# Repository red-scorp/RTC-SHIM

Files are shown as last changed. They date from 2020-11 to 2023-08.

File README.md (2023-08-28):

# RTC-SHIM project

RTC-SHIM (mini-HAT), a DS3231 battery driven real-time clock for Raspberry Pi.

"How did it come to this?" you may ask.
The answer is simple.
I was pissed off by the fact the several Pis I have all have the same issue.
They lose time information when they switched off and need Internet to set proper time again.
The obvious reason for this is lack of RTC chip and backup battery to count time when main CPU of Pi is off.
This is how it's done in all modern PCs and notebooks (and Macs too).
I've searched Internet and found no solution which suits my needs.

- The RTC board should be mounted on 40-pin connector of Raspberry Pi (like 2, 3, 4, zero have).
- The board should be mechanically and electrically compatible with all modern Pis (3+, 4, zero WH).
- The board should be mounted inside or outside the Pi's case.
- There should be possible to put some Pi HAT (Hardware Attached on Top) on top of the board (like LCD display, LoRa, LEDs array or 3G/4G modem HATs).
- The board should be obviously small enough to fit in case of Pi.
- The board should have a battery holder or/and a common notebook BIOS battery connector.
- The board should be easy to setup under Pi's Linux (like Raspbian or Ubuntu).
- The board should be cheap to buy or/and easy to manufacture by (my) hand at home.

And gradually I came with few designs presented here.

## RTC-SHIM

Raspberry Pi 40-pin **RTC-SHIM** mini-HAT.

Preview:

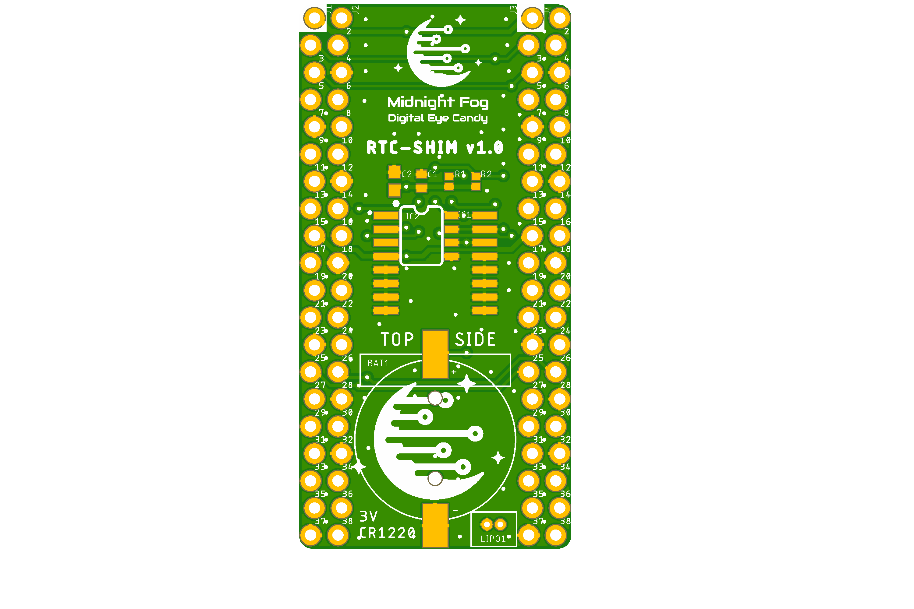
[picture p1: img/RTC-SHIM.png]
RTC-SHIM preview


[Schematics in PDF format](doc/RTC-SHIM.pdf)

Features:

- DS3231 RTC chip
- double footprint for larger and smaller versions of the chip
- CR1220 3V battery
- locked Pi headers
- double set of Pi headers (for inside and outside mount)
- I2C0/I2C1 bus selection
- can be used as SHIM (no headers) or HAT (with headers)
- optional external notebook BIOS battery connector

CAM files are available.

## RTC-mini-flip-SHIM

Raspberry Pi **RTC-mini-flip-SHIM** micro-HAT.

Preview:

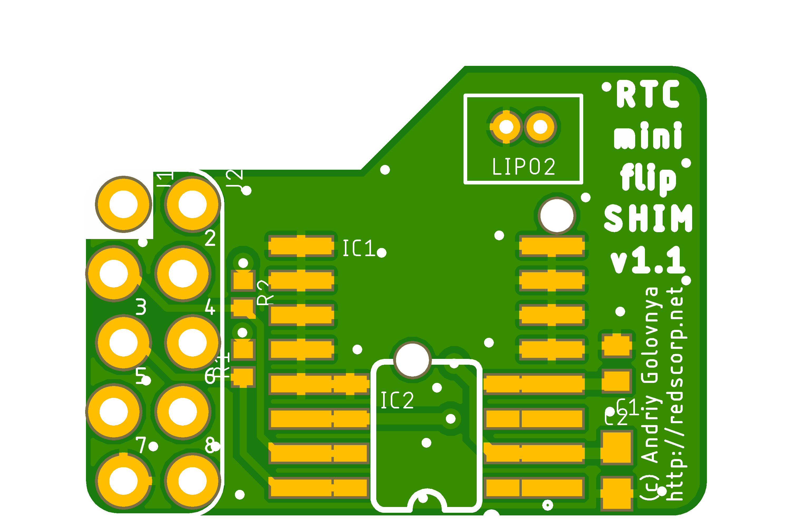
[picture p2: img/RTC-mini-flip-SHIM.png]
RTC-mini-flip-SHIM preview


[Schematics in PDF format](doc/RTC-mini-flip-SHIM.pdf)

Features:

- DS3231 RTC chip
- double footprint for larger and smaller versions of the chip
- CR1220 3V battery
- locked Pi headers
- double mount on Pi headers (for inside and outside mount)
- very small size
- fits on 26- and 40-pin Pi headers
- optional external notebook BIOS battery connector (both side mount possible)

CAM files are available.

## RTC-zero-SHIM

Raspberry Pi zero 40-pin **RTC-zero-SHIM** mini-HAT.

Preview:

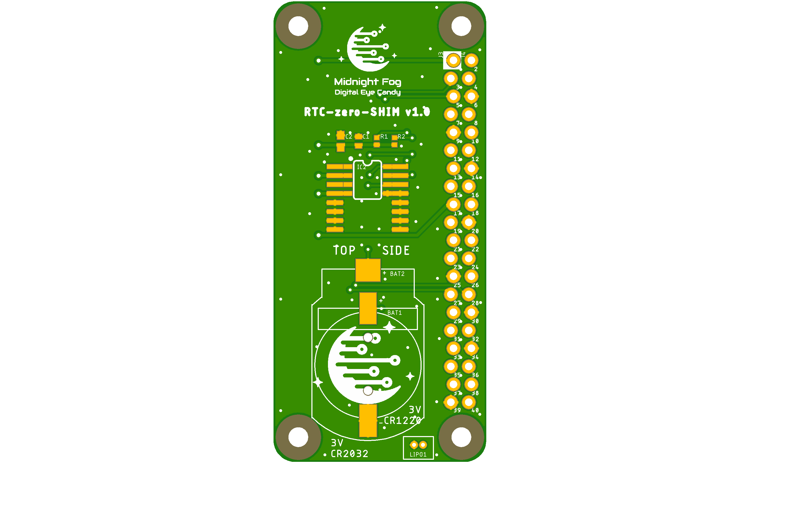
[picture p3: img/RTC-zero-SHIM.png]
RTC-zero-SHIM preview


[Schematics in PDF format](doc/RTC-zero-SHIM.pdf)

Features:

- DS3231 RTC chip
- double footprint for larger and smaller versions of the chip
- CR2032/CR1220 3V battery
- locked Pi headers
- Pi zero board style
- I2C0/I2C1 bus selection
- can be used as SHIM (no headers) or HAT (with headers)
- optional external notebook BIOS battery connector

CAM files are available.

## BOM

Bill Of Materials is currently available only for LCSC Electronic Components Distributor, which is probably cheapest anyway.

### LCSC BOM

|Designator  |Part/Value  |Package/Footprint |LCSC # |
|---|---|---|---|
|BAT1 |CR1220-2 |SMD |C70381 |
|BAT2 |BS-8-1 |SMD |C70378 |
|C1\*\* |Cap. 100nF  |0402 |C1525  |
|C2\*\* |Cap. 1uF |0603 |C15849 |
|IC1\* |DS3231SN#T&R|SOIC-16_300mil |C9866  |
|IC2\* |DS3231MZ+TRL|SOIC-8_150mil |C107410|
|LIPO1, LIPO2|A1251WV-2P  |Through Hole,P=1.25mm |C225090|
|R1, R2\*\*  |Res. 10K |0402 |C25744 |

\*) Only one of chips should be installed, either IC1 or IC2.
\*\*) These passive components are optional but it's recommended to install them.

## Links

- [pinout.xyz](https://pinout.xyz/) - a brilliant resource on topic of Pi's pinout and HATs.
- [raspberrypi/hats](https://github.com/raspberrypi/hats) - Pi's HAT specification.
- [RPI_RTC_Module_SKU:EP-0016](https://wiki.52pi.com/index.php/RPI_RTC_Module_SKU:EP-0016) - some RTC schematics and setup info.
- [Raspberry Pi RTC: Adding a Real Time Clock](https://pimylifeup.com/raspberry-pi-rtc/) - RTC setup info.

## How to help

Your contributions as code, resources, or finances are welcome! Please contact me directly via email at andriy.golovnya@gmail.com or through my [GitHub profile](https://github.com/red-scorp).

If you'd like to make a financial contribution, you can donate via [PayPal](http://paypal.me/redscorp) or [Ko-Fi](http://ko-fi.com/redscorp). Your support is greatly appreciated.

Thanks in advance!

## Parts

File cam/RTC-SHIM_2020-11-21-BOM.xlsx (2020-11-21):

Qty | Designator | Footprint | Comment | LCSC Part # | Description
1 | C1 | 0402 | 100nF | C1525 (https://lcsc.com/product-detail/Multilayer-Ceramic-Capacitors-MLCC-SMD-SMT_SAMSUNG_CL05B104KO5NNNC_100nF-104-10-16V_C1525.html/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) | CAPACITOR
2 | R1, R2 | 0402 | 10K | C25744 (https://lcsc.com/product-detail/Chip-Resistor-Surface-Mount_Uniroyal-Elec-0402WGF1002TCE_C25744.html/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) | RESISTOR
1 | C2 | 0603 | 1uF | C15849 (https://lcsc.com/product-detail/Multilayer-Ceramic-Capacitors-MLCC-SMD-SMT_SAMSUNG_CL10A105KB8NNNC_1uF-105-10-50V_C15849.html/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) | CAPACITOR
1 | IC1 | SOIC-16_7.5x10.3x1.27P | DS3231M+TRL | C37663 (https://lcsc.com/product-detail/Real-time-Clocks_MAXIM_DS3231M-TRL_DS3231M-TRL_C37663.html/?href=jlc-SMT) | RTC Chip

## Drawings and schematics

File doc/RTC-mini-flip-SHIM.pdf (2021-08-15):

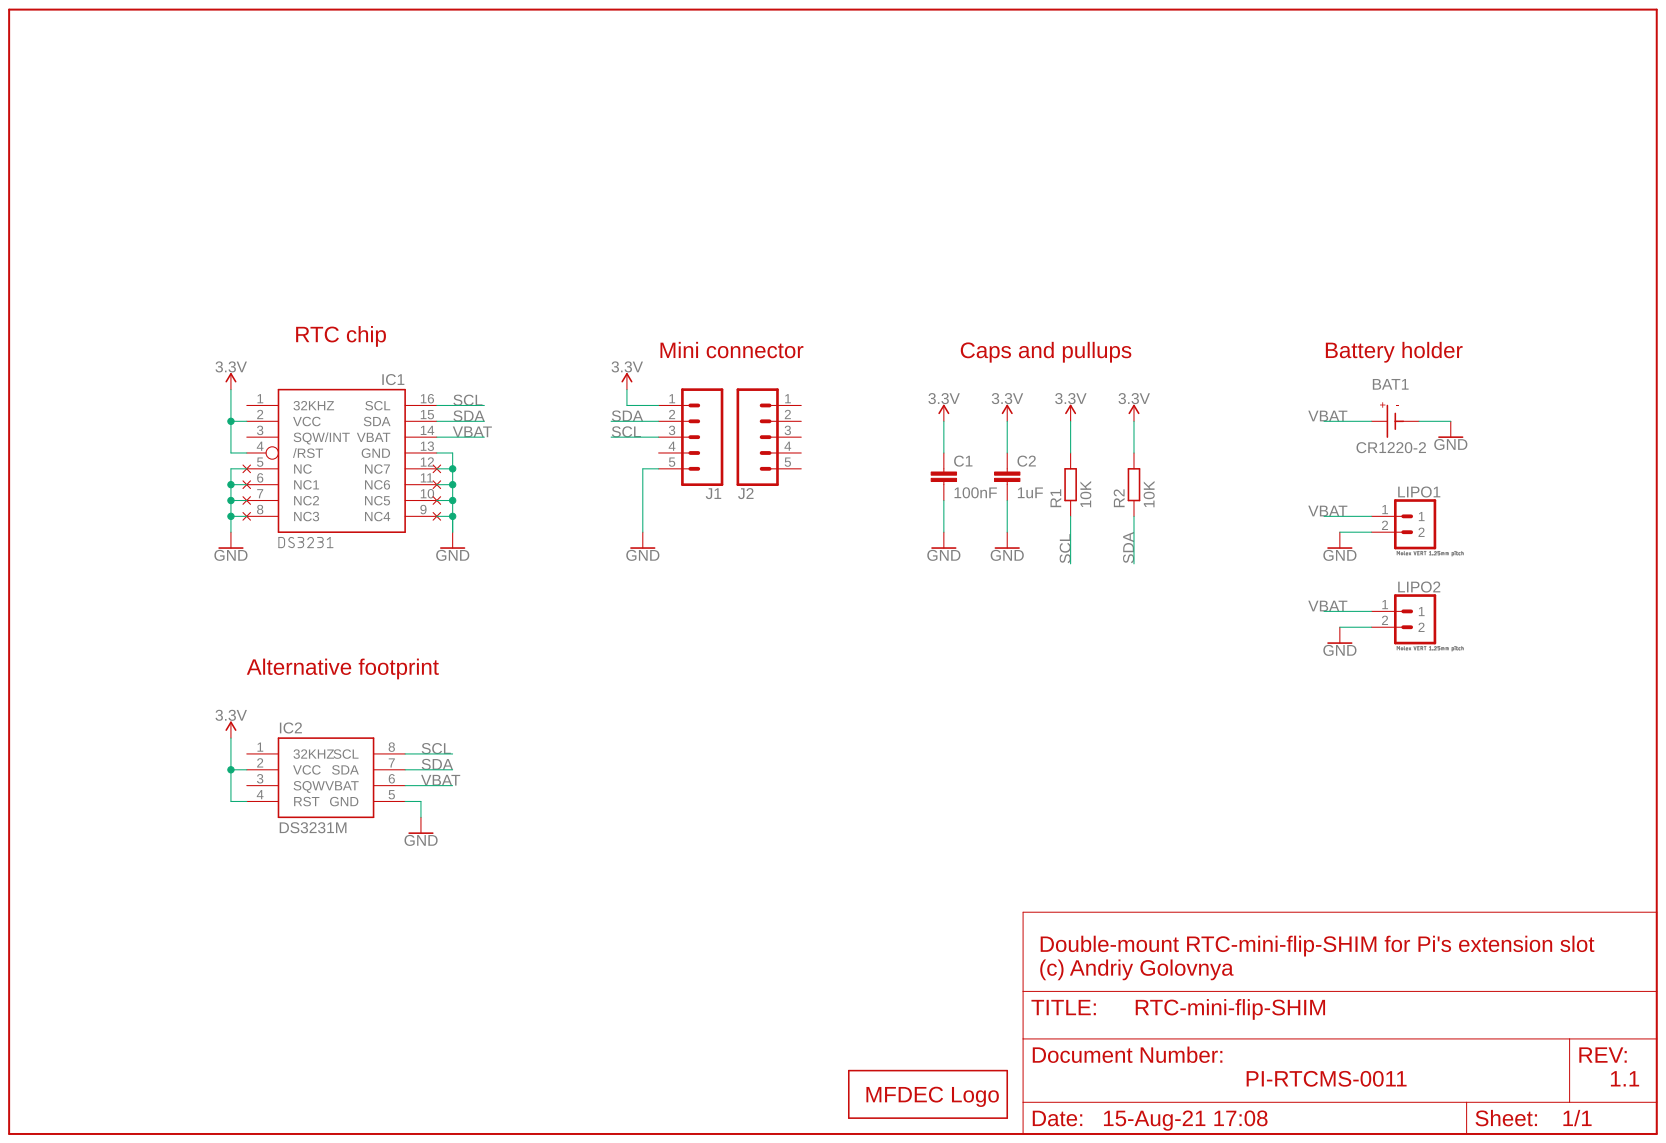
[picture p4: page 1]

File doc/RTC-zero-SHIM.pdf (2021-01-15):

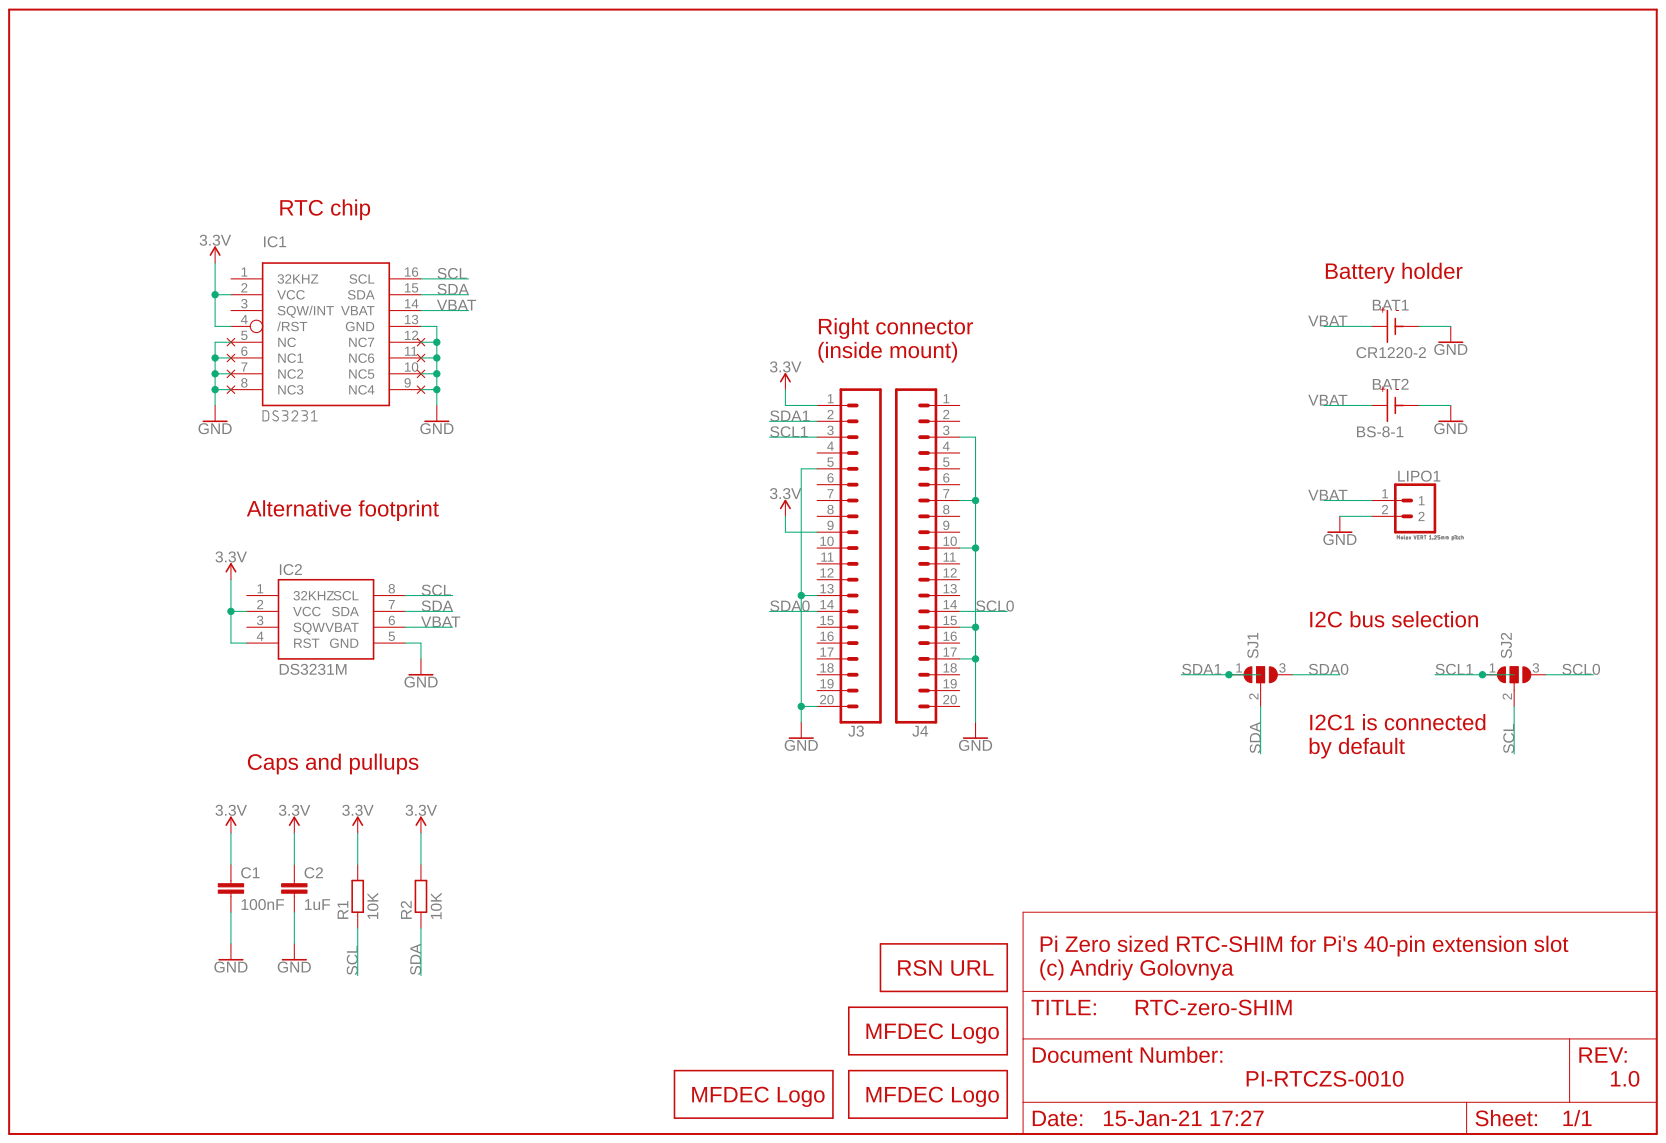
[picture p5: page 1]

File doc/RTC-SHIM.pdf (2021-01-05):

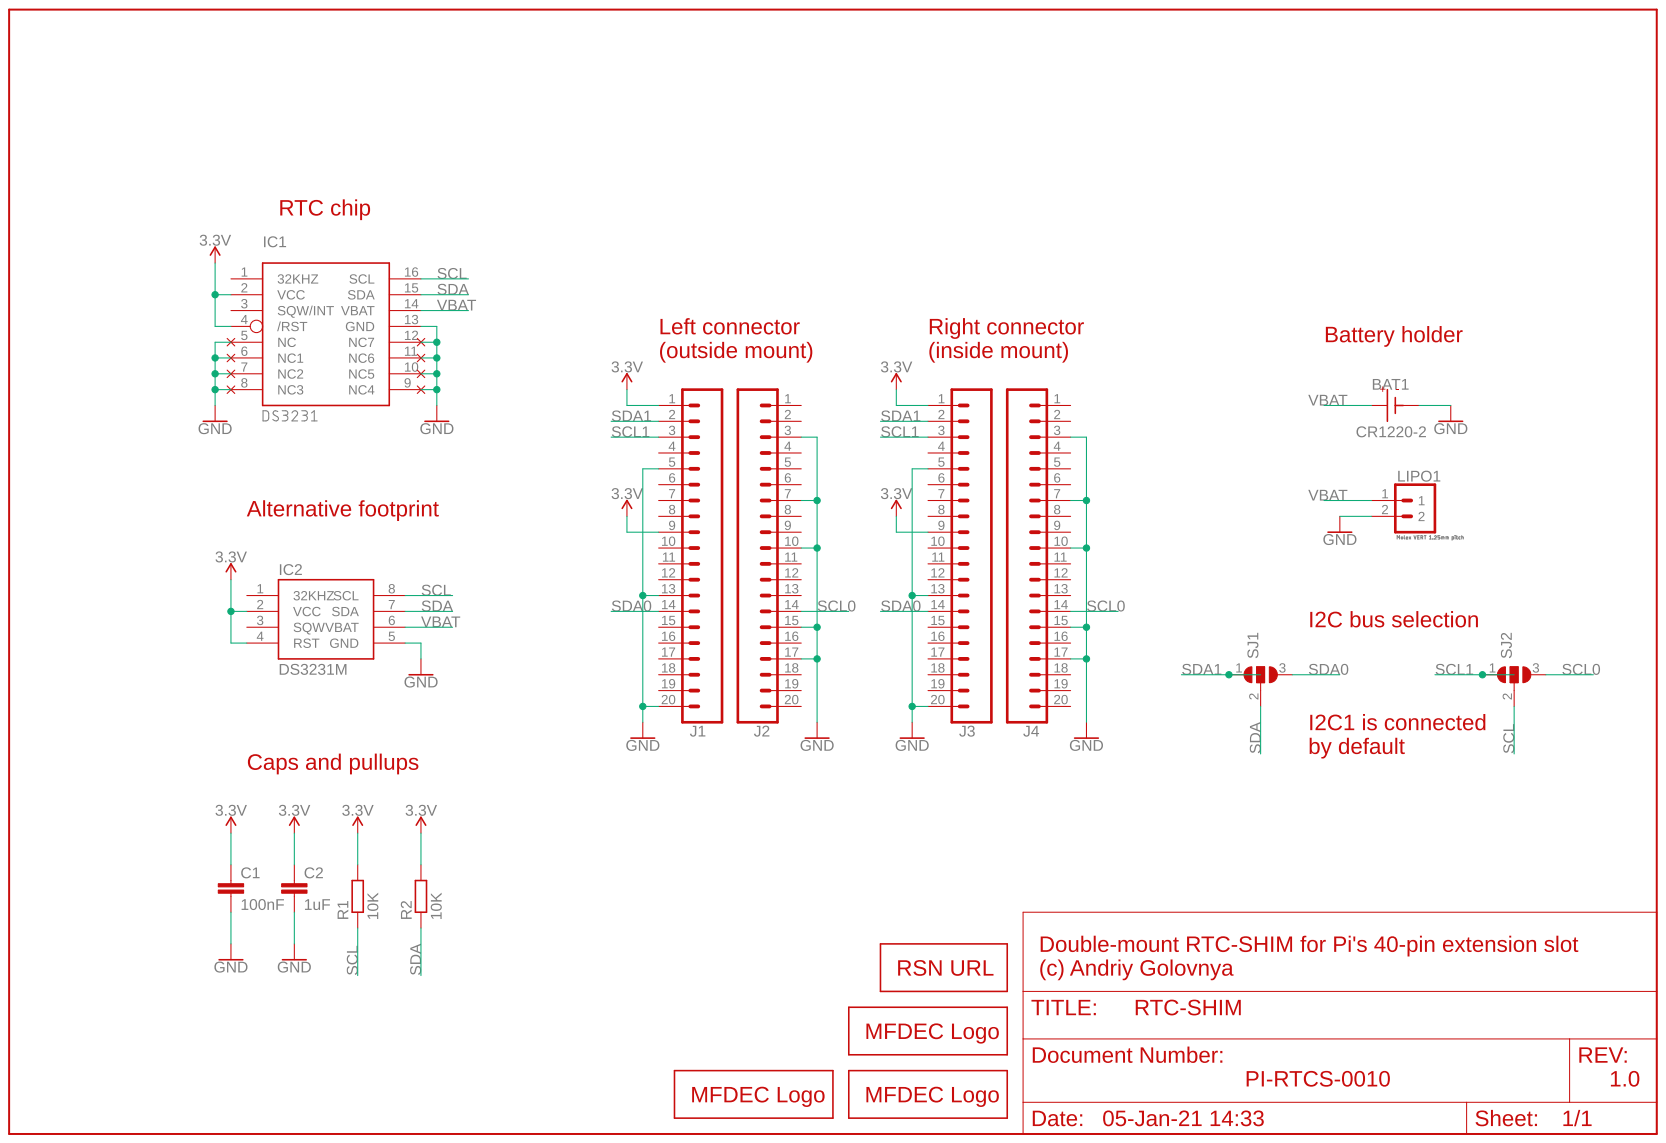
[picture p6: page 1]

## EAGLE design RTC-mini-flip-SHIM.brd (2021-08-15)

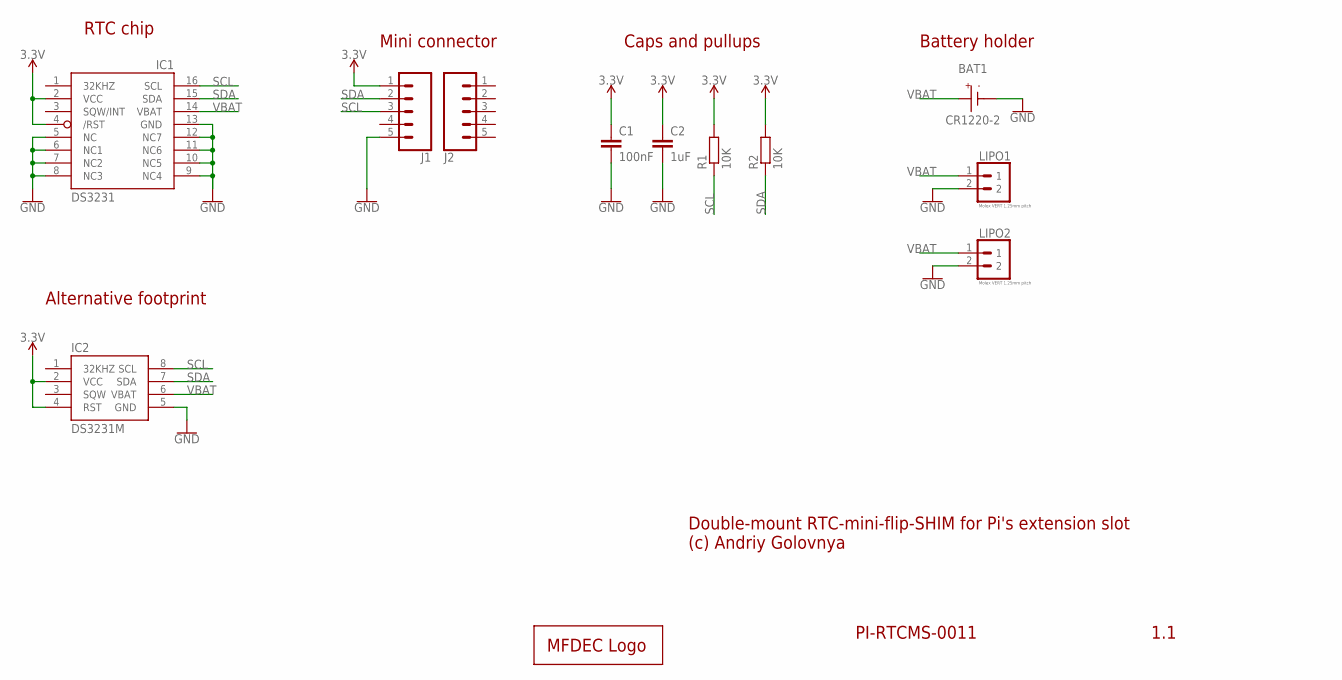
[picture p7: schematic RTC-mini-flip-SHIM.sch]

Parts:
BAT1: CR1220-2
C1: 100nF; C0402
C2: 1uF; C0603
IC1: DS3231/SO; SO16W
IC2: DS3231M; SO08
J1, J2: CONN_05LOCK; 1X05_LOCK
LIPO1, LIPO2: Molex VERT 1.25mm pitch; _MOLEX-0530470210_VERT_PITCH-1.25MM
LOGO1: MFDECLOGO_L_10MM; MFDEC_L_10MM
R1, R2: 10K; R0402

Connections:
3.3V: C1.1, C2.1, IC1.2 (VCC), IC1.4 (/RST), IC2.2 (VCC), IC2.4 (RST), J1.1, R1.2, R2.2
GND: BAT1.BAT-, C1.2, C2.2, IC1.5 (NC), IC1.6 (NC1), IC1.7 (NC2), IC1.8 (NC3), IC1.9 (NC4), IC1.10 (NC5), IC1.11 (NC6), IC1.12 (NC7), IC1.13 (GND), IC2.5 (GND), J1.5, LIPO1.2, LIPO2.2
SCL: IC1.16 (SCL), IC2.8 (SCL), J1.3, R1.1
SDA: IC1.15 (SDA), IC2.7 (SDA), J1.2, R2.1
VBAT: BAT1.BAT+, IC1.14 (VBAT), IC2.6 (VBAT), LIPO1.1, LIPO2.1

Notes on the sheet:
1.1
PI-RTCMS-0011
Double-mount RTC-mini-flip-SHIM for Pi's extension slot (c) Andriy Golovnya
RTC chip
Caps and pullups
Mini connector
Battery holder
Alternative footprint

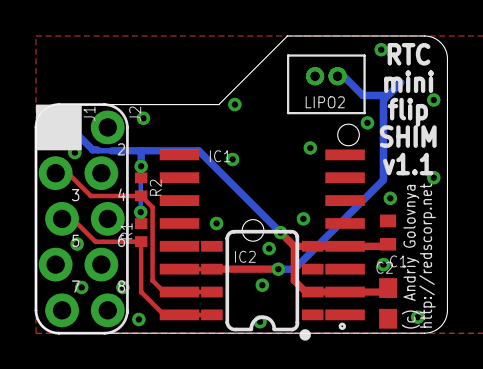
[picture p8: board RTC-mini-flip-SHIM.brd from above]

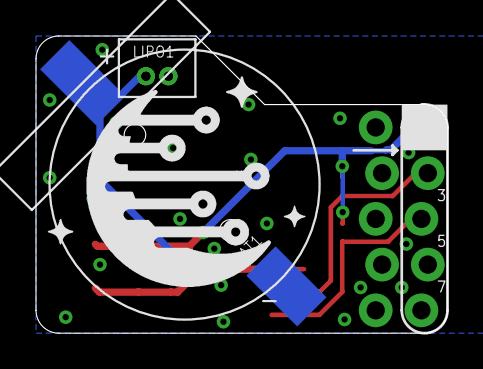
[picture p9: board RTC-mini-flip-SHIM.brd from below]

Board: 2 copper layers, 22.9 x 16.5 mm, 12 parts (3 on the bottom side), 5 nets.

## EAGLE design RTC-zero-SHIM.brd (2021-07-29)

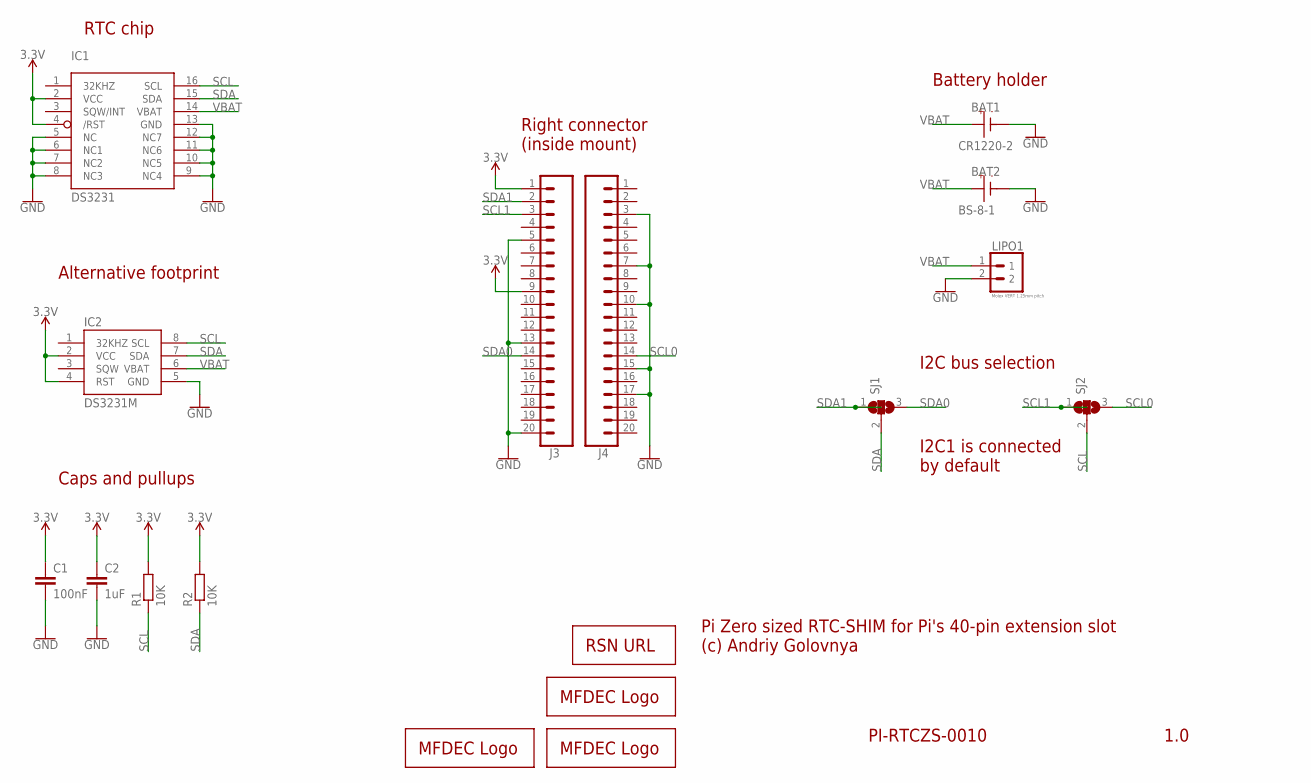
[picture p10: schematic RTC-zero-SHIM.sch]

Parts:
BAT1: CR1220-2
BAT2: BS-8-1
C1: 100nF; C0402
C2: 1uF; C0603
IC1: DS3231/SO; SO16W
IC2: DS3231M; SO08
J3, J4: CONN_20LOCK; 1X20_LOCK
LIPO1: Molex VERT 1.25mm pitch; _MOLEX-0530470210_VERT_PITCH-1.25MM
LOGO1: MFDECLOGO_SQ_8MM; MFDEC_SQ_8MM
LOGO2: MFDECLOGO_L_30MM; MFDEC_L_30MM
LOGO3: RSNURL_QR_10MM
LOGO4: MFDECLOGO_L_10MM; MFDEC_L_10MM
R1, R2: 10K; R0402
SJ1, SJ2: SJ2; SJ_2

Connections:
3.3V: C1.1, C2.1, IC1.2 (VCC), IC1.4 (/RST), IC2.2 (VCC), IC2.4 (RST), J3.1, J3.9, R1.2, R2.2
GND: BAT1.BAT-, BAT2.BAT-, C1.2, C2.2, IC1.5 (NC), IC1.6 (NC1), IC1.7 (NC2), IC1.8 (NC3), IC1.9 (NC4), IC1.10 (NC5), IC1.11 (NC6), IC1.12 (NC7), IC1.13 (GND), IC2.5 (GND), J3.5, J3.13, J3.20, J4.3, J4.7, J4.10, J4.15, J4.17, LIPO1.2
SCL: IC1.16 (SCL), IC2.8 (SCL), R1.1, SJ2.2
SCL0: J4.14, SJ2.3
SCL1: J3.3, SJ2.1
SDA: IC1.15 (SDA), IC2.7 (SDA), R2.1, SJ1.2
SDA0: J3.14, SJ1.3
SDA1: J3.2, SJ1.1
VBAT: BAT1.BAT+, BAT2.BAT+, IC1.14 (VBAT), IC2.6 (VBAT), LIPO1.1

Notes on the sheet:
1.0
PI-RTCZS-0010
Pi Zero sized RTC-SHIM for Pi's 40-pin extension slot (c) Andriy Golovnya
RTC chip
Caps and pullups
Right connector (inside mount)
I2C bus selection
I2C1 is connected by default
Battery holder
Alternative footprint

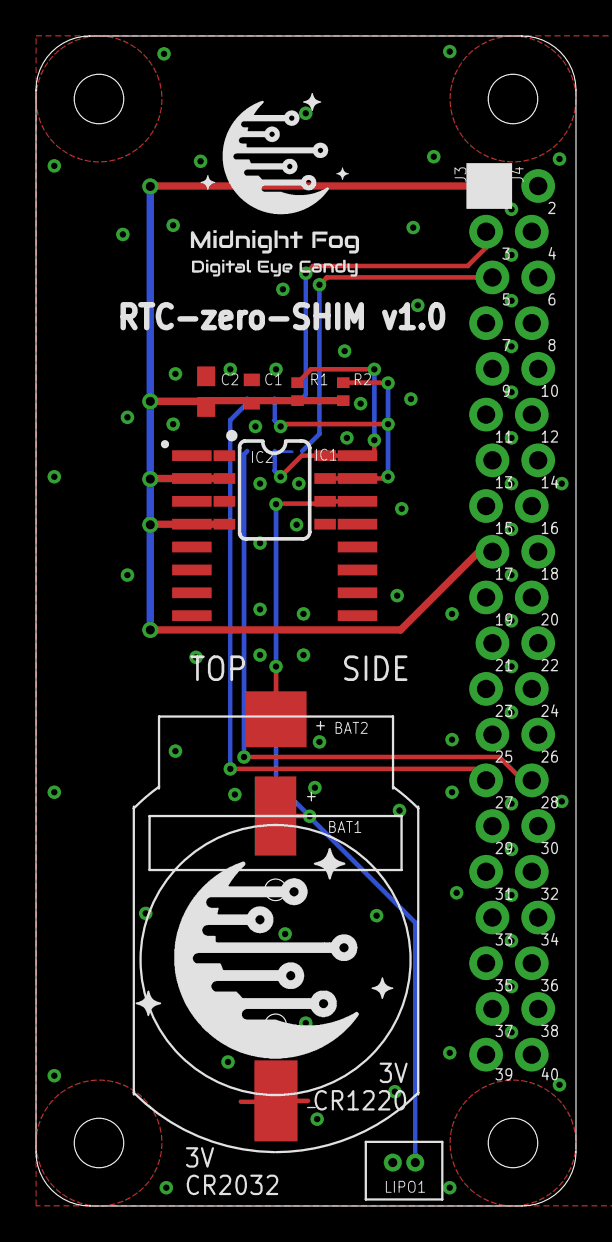
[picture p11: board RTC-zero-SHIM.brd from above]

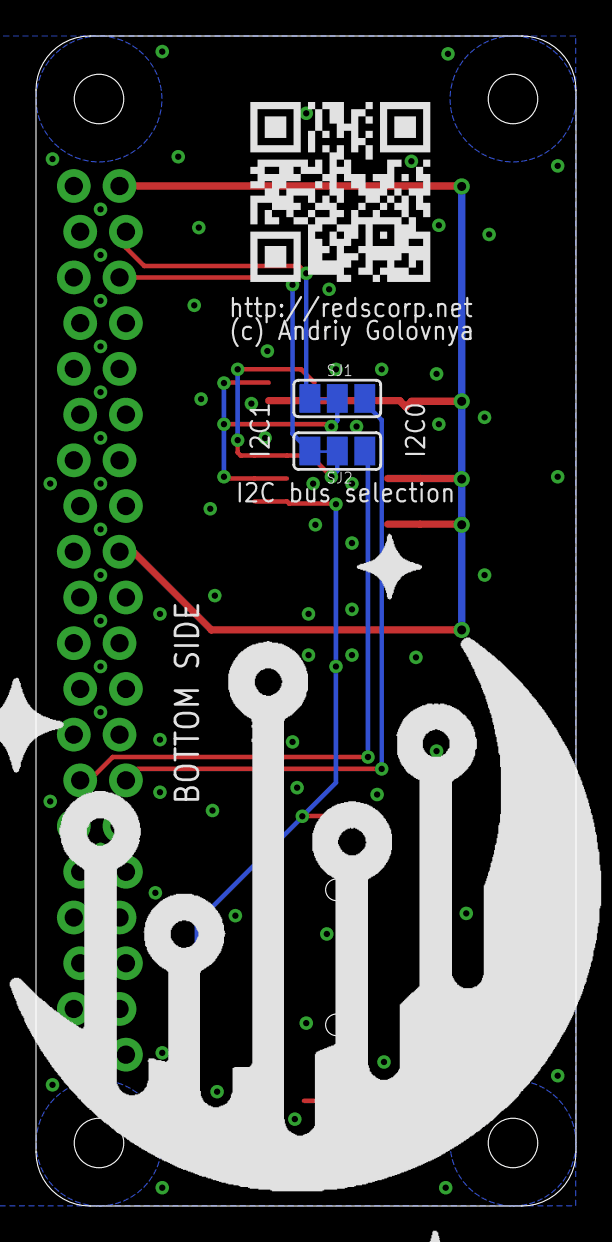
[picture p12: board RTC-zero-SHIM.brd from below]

Board: 2 copper layers, 30.0 x 65.0 mm, 17 parts (4 on the bottom side), 9 nets.

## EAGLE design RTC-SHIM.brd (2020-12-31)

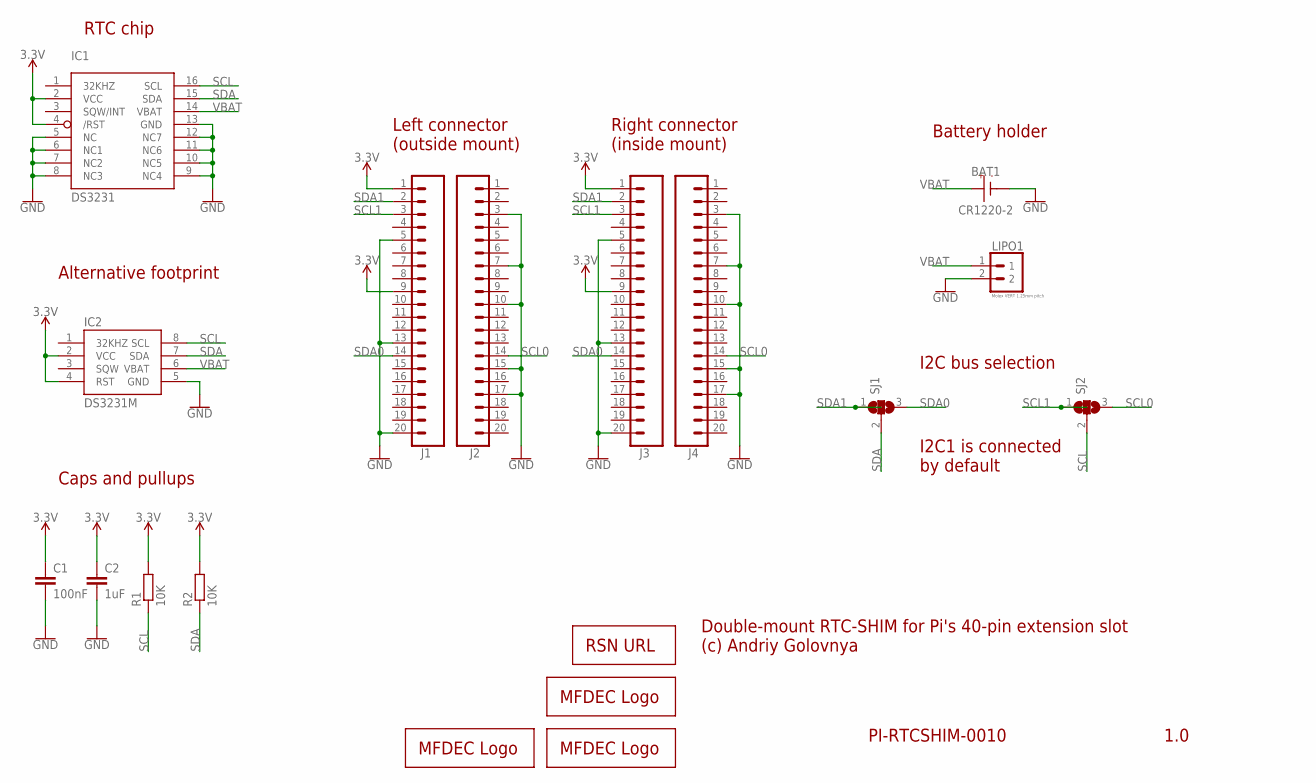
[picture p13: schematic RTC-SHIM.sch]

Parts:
BAT1: CR1220-2
C1: 100nF; C0402
C2: 1uF; C0603
IC1: DS3231/SO; SO16W
IC2: DS3231M; SO08
J1, J2, J3, J4: CONN_20LOCK; 1X20_LOCK
LIPO1: Molex VERT 1.25mm pitch; _MOLEX-0530470210_VERT_PITCH-1.25MM
LOGO1: MFDECLOGO_SQ_8MM; MFDEC_SQ_8MM
LOGO2: MFDECLOGO_L_20MM; MFDEC_L_20MM
LOGO3: RSNURL_QR_10MM
LOGO4: MFDECLOGO_L_10MM; MFDEC_L_10MM
R1, R2: 10K; R0402
SJ1, SJ2: SJ2; SJ_2

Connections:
3.3V: C1.1, C2.1, IC1.2 (VCC), IC1.4 (/RST), IC2.2 (VCC), IC2.4 (RST), J1.1, J1.9, J3.1, J3.9, R1.2, R2.2
GND: BAT1.BAT-, C1.2, C2.2, IC1.5 (NC), IC1.6 (NC1), IC1.7 (NC2), IC1.8 (NC3), IC1.9 (NC4), IC1.10 (NC5), IC1.11 (NC6), IC1.12 (NC7), IC1.13 (GND), IC2.5 (GND), J1.5, J1.13, J1.20, J2.3, J2.7, J2.10, J2.15, J2.17, J3.5, J3.13, J3.20, J4.3, J4.7, J4.10, J4.15, J4.17, LIPO1.2
SCL: IC1.16 (SCL), IC2.8 (SCL), R1.1, SJ2.2
SCL0: J2.14, J4.14, SJ2.3
SCL1: J1.3, J3.3, SJ2.1
SDA: IC1.15 (SDA), IC2.7 (SDA), R2.1, SJ1.2
SDA0: J1.14, J3.14, SJ1.3
SDA1: J1.2, J3.2, SJ1.1
VBAT: BAT1.BAT+, IC1.14 (VBAT), IC2.6 (VBAT), LIPO1.1

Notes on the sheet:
1.0
PI-RTCSHIM-0010
Double-mount RTC-SHIM for Pi's 40-pin extension slot (c) Andriy Golovnya
RTC chip
Caps and pullups
Left connector (outside mount)
Right connector (inside mount)
I2C bus selection
I2C1 is connected by default
Battery holder
Alternative footprint

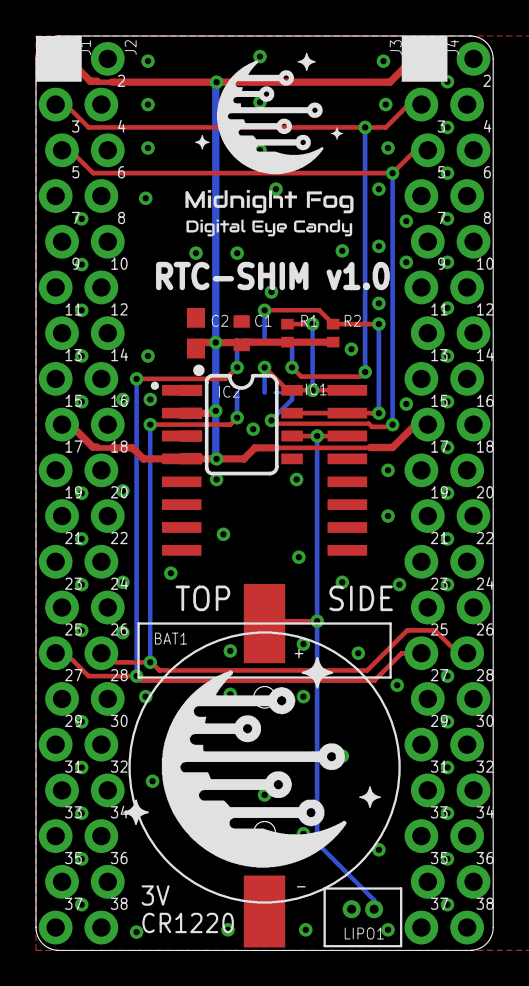
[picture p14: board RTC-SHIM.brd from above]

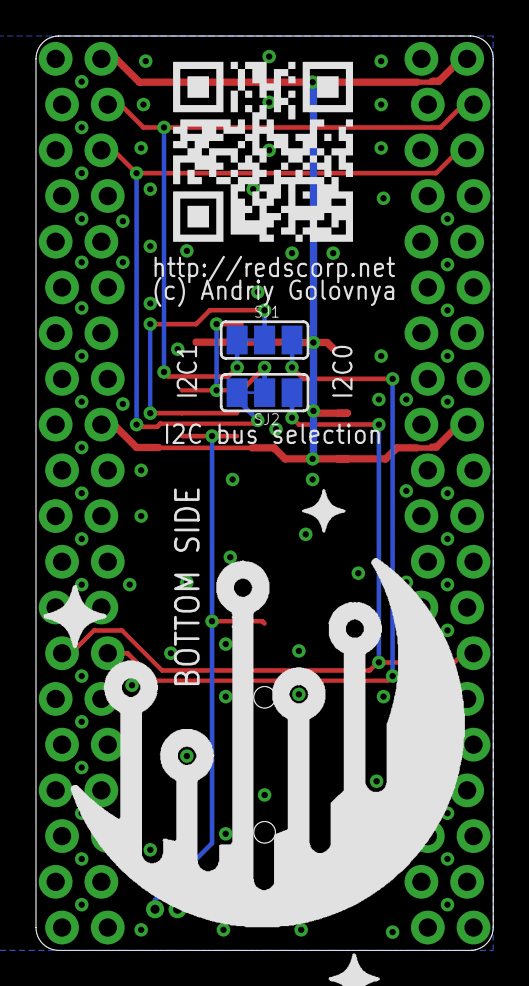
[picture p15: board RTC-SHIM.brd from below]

Board: 2 copper layers, 25.4 x 50.8 mm, 18 parts (4 on the bottom side), 9 nets.

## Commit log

2020-11-18 Add basic components for universal RTC SHIM for Pi
    [RTC-SHIM.sch]
2020-11-19 Add 40 pin connectors and solder joins fro I2C bus selection. Add basic board layout.
    [RTC-SHIM.brd, RTC-SHIM.sch]
2020-11-20 Added Battery holder and some logos and texts.
    [RTC-SHIM.brd, RTC-SHIM.sch]
2020-11-20 Moved stuff around a little bit.
    [RTC-SHIM.brd, RTC-SHIM.sch]
2020-11-21 Trace the board. Add CAM files.
    [RTC-SHIM.brd, RTC-SHIM.sch]
2020-11-21 Added BOM and PnP
    [RTC-SHIM_2020-11-21-BOM.xlsx, RTC-SHIM_2020-11-21-PnP.xlsx]
2020-11-22 Add few texts. Move some traces around. Updated description.
    [RTC-SHIM.brd, RTC-SHIM.sch]
2020-11-24 Add RTC-mini-flip-SHIM.
    [RTC-mini-flip-SHIM.brd, RTC-mini-flip-SHIM.sch]
2020-11-25 Removed unneeded traces. generated new CAM.
    [RTC-SHIM.brd, RTC-mini-flip-SHIM.brd]
2020-11-25 Added battery connector. Generated CAM.
    [RTC-SHIM.brd, RTC-SHIM.sch, RTC-mini-flip-SHIM.brd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]
2020-11-26 Add CAM for mini SHIM.
    [RTC-mini-flip-SHIM.brd]
2020-11-26 Add battery connector to the front of mini SHIM too. Generate new CAM.
    [RTC-mini-flip-SHIM.brd, RTC-mini-flip-SHIM.sch]
2020-11-26 Updated readmes with CMOS battery connector
2020-11-27 Add schematics in PDF format
2020-11-27 Add board preview images.
2020-11-30 Update README.md
    Add LCSC BOM
2020-12-02 Add pin numbers on silk.
    [RTC-SHIM.brd, RTC-mini-flip-SHIM.brd]
2020-12-11 Moved some stuff around. Add second footprint. Moved battery away from center for better flipability.
    [RTC-SHIM.brd, RTC-SHIM.sch, RTC-mini-flip-SHIM.brd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]
2020-12-13 Changed mini SHIM layout. Traced mini SHIM.
    [RTC-mini-flip-SHIM.brd, RTC-mini-flip-SHIM.sch]
2020-12-13 Use more locking pin headers. Moved some traces.
    [RTC-SHIM.brd, RTC-SHIM.sch, RTC-mini-flip-SHIM.brd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]
2020-12-18 Generated new PNG board previews.
2020-12-21 Added RTC-zero-SHIM design.
    [RTC-zero-SHIM.brd, RTC-zero-SHIM.sch]
2020-12-21 Added new PDF schematics.
2020-12-21 Fixed descriptions for battery type.
2020-12-31 Adjusted some traces differently. Generated preview PNG. Generated new CAM.
    [RTC-SHIM.brd]
2021-01-05 Simplified document names. Generated PDF schematics.
    [RTC-SHIM.sch, RTC-mini-flip-SHIM.sch, RTC-zero-SHIM.sch]
2021-01-08 Moved battery holder and lipo connector a bit down to improve compatibility with other boards.
    [RTC-zero-SHIM.brd]
2021-01-10 Added link to raspberrypi/hats
2021-01-15 Added second batter holder as alternative. Generated CAM. Generated PDF schematics. Generated PNG preview image.
    [RTC-zero-SHIM.brd, RTC-zero-SHIM.sch]
2021-07-29 Make round cutouts in screwing area. Generated CAM files. Generated PNG previews.
    [RTC-zero-SHIM.brd]
2021-08-15 Moved battery socket to another side to not collide with CPU heat sink. Generated CAM files.
    [RTC-mini-flip-SHIM.brd, RTC-mini-flip-SHIM.sch]
2021-08-15 Generated PDF schematics.

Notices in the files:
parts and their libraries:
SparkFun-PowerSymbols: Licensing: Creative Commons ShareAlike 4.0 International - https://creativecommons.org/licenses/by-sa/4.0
